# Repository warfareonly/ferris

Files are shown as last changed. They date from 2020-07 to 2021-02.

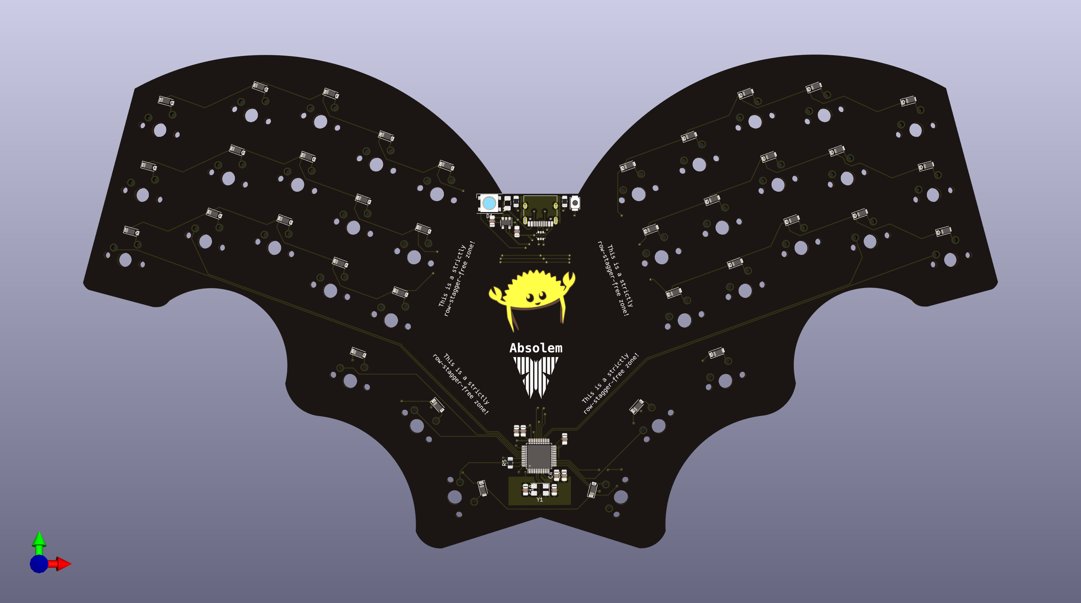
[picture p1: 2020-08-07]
absolem_layout/ferris_absolem_front.png

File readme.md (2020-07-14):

Meet Ferris, a minimalistic keyboard
====================================

Named after the Rustlang mascott, ferris is a 34 keys split keyboard that tries to be about as cute as its namesake.

Ferris
Ferris low front
Ferris low back

Ferris is minimalistic: it aims to be a functional, ergonomic keyboard that is pleasing to use as a daily driver. It only supports choc keyswitches, although it would be easy to make a MX version if there was interest.

It is fully Open-Source: the kicad files are released under [the solderpad license, version 2.1](LICENSE). The firmware, contributed to [the QMK project](https://github.com/qmk/qmk_firmware/) is released under the GPL.

Design philosophy
-----------------

The Ferris was designed around this set of goals:
* Comfort
* Aesthetics
* Portability
* Ease of assembly
* Low-Cost
* Low-Profile
* 34 keys
* Hackable
* USB-C
* No compromise

and this set of non-goals:
* Reversible PCB used for both hands
* Pro-micro/Elite C/Proton C support
* Hot-Swap support
* Multi-switches support
* Support for any feature (RGB, OLED, encoders, ...) that is not of interest to the user

You may read more about how each feature (and mostly lack thereof) contributes to these goals [in this write up](docs/design_philosophy.md) once described as "overly long and almost pretentious" :)

Technical details
-----------------

### Base variant, rev 0.1

This describes the first ever iteration of the Ferris keyboard: a plain pcb with support for choc switches, and the same layout as the Kyria (but limited to 34 keys).

* USB C
* 34 keys (3x5 + 2 thumb keys per hand)
* Split
* Atmega32u4 microcontroller on the left hand side
* MCP23017 on the right hand side
* A 4 poles jack cable carries data between halves using the i2c protocol
* The diodes live under the switches where they are snuggly hidden from sight
* No holes through the PCB. The intent is to use it case-less.
* Switches are spaced by 19mm from each other in each direction (almost exactly what's known as MX spacing [19.05x19.05]). This allows for a wider variety of compatible keycaps for the price of gaps for certain keycaps that respect the Kailh choc specification
* Columnar stagger identical to the one on the Kyria

### Ferris low variant, rev 0.1

* Same as the base variant with major change that the footprints are for Kailh PG1232 instead of choc for an even lower profile
* Copper pad adapted to ducking Ferris for theme
* Silkscreen changed to display schematics from the PG1232 switch
* Recommended PCB solder mask color is blue instead of white so the silkscreen gives vibes of a blueprint
* Name of the board updated to "Ferris low" instead of "Ferris"

### Upcoming changes

In rev 0.2, I would like to implement the following changes:

* Microcontroller: [Arm STM32F030F4P6TR](https://lcsc.com/product-detail/Others_STMicroelectronics_STM32F030F4P6TR_STMicroelectronics-STM32F030F4P6TR_C89040.html) instead of [Atmega32u4](https://lcsc.com/product-detail/ATMEL-AVR_ATMEL_ATMEGA32U4-AU_ATMEGA32U4-AU_C44854.html)
  * Cheaper: 0.83$ instead of $3.63, less unused pins, easier to solder, more flash, more ram, better rust support for possible pure rust firmware
* IO Expander: [PCA9539PW ](https://lcsc.com/product-detail/I-O-Expansion_NXP_PCA9539PW_PCA9539PW_C129516.html) instead of [MCP23017](https://lcsc.com/product-detail/Interface-ICs_MICROCHIP_MCP23017-E-SO_MCP23017-E-SO_C47023.html)
  * Cheaper 0.76$ instead of 1.56$
* Spacing: 0.18x0.19 instead of 0.19x0.19
  * Avoids gaps with keycaps that conform with the Kailh specifications
  * More ergonomic as fingers don't have to move as far up and down
  * Con: Looses compatibility to some keycaps
* Ferris MX:
  * I would like to also do a run with MX only footprints for anyone interested
* Ferris tent:
  * I would like to add four mounting holes on each hand to support the tenting puck that Thomas Baart at splitkb.com is currently designing

How to I print one?
-------------------

For a given version, you will find a release in this repository containing a zip file with the gerber files. This should be ready to send to a PCB manufacturer for assembly.
The repository also contains a bill of materials (bom.csv) with a list of the components you need and their reference number on LCSC.com. You may use another vendor for the components, as long as you make sure to get components that are equivalent.

How do I assemble one?
----------------------

Here is where the components go on the pcb:
components around the microcontroller
components around the usb c and the io expander

Most of these components are smd mounted. They can be soldered in with hot air and solder paste or with a soldering iron, solder wire and flux.
I have found it easier to control how much solder I use with a soldering iron.

Here are some key pieces of advice I can give from my experience assembling 3 of them so far:
* Be mindful of the orientation for the components that are polarized:
  * Diodes: cathode bar on the right side for both pcbs
  * Crystal: text readable looking at it from the controller
  * Controller: pin 1 dot indicator in the top right
  * IO expander: pin 1 dot indicator in the top left
* Use a wedge tip or other tip with a large enough surface. Pointy is harder.
* Don't use too much solder or you will have to wick it away and start again.
  * This especially applies to the USB C area and the microcontroller.
* Don't be shy on the flux: it really helps the solder flow where it should and keep away from surfaces it shouldn't go to.
* Don't use too much heat to avoid damaging the components. I've had good results with 350C for unleaded rosin core solder wire.
* Don't touch any component for too long with the iron to avoid heat damage. If you're not getting it right in a few seconds, let it cool down add more flux and try again. 
* Be sure to test every diode is properly soldered before soldering on the switches as the diodes are located under the switches and won't be accessible later on.
* I have found it easier to solder the crystal with hot air as it is hard to reach the solder from under it with an iron. Your mileage may vary

I took many pictures while building a board. If you want to build a Ferris while following along,
Part 1:
[build log, part 1](https://imgur.com/gallery/jYbxkxE)
Part 2:
[build log, part 2](https://imgur.com/gallery/gs19F6E)

Where is the firmware?
----------------------

For now, the Ferris keyboard is powered by QMK. Firmware for it is available [in this PR](https://github.com/qmk/qmk_firmware/pull/9634) and should make it upstream once the review process has taken its course.

The default keymap is very minimalistic. I will come up with something fancier in due time.

Status:
-------
v 0.1 is confirmed to work: I have printed 5 on jlcpcb.com and assembled 3. I have flashed the firmware on all of these and made sure that all keys are recognized as intended. I am also typing these words on a Ferris.

Here is a short demo of a working Ferris:
[typing test](https://i.imgur.com/E8Wipxz.mp4)

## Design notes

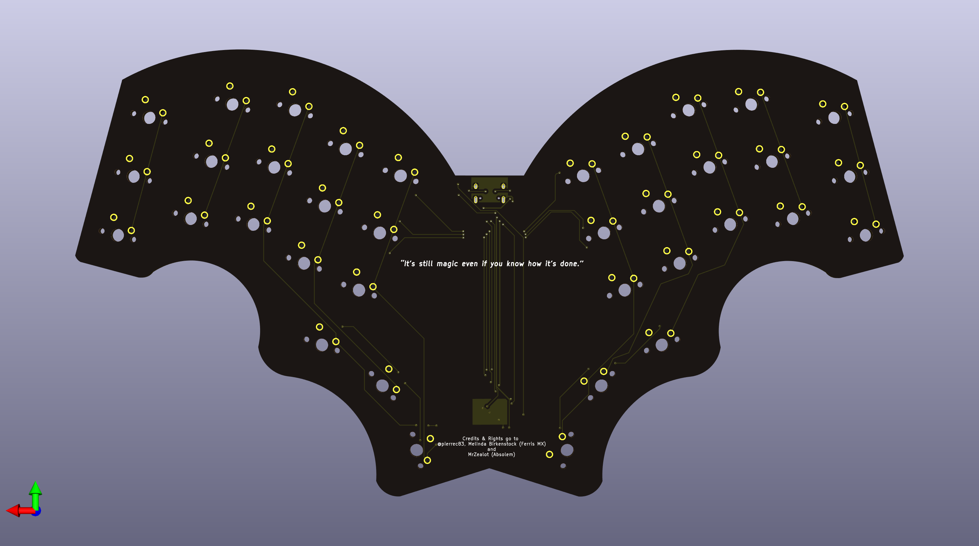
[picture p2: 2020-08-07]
absolem_layout/ferris_absolem_back.png

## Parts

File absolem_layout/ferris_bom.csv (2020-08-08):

Source: | /home/bharat/keyboard/ferris/absolem_layout/ferris.sch
Date: | Sat 08 Aug 2020 18:04:10 CEST
Tool: | Eeschema 5.1.6
Component Count: | 97
Ref | Value | Footprint | Datasheet | Manufacturer | Vendor
C1 | 1u | Capacitor_SMD:C_0805_2012Metric_Pad1.15x1.40mm_HandSolder | ~
C2 | 1u | Capacitor_SMD:C_0805_2012Metric_Pad1.15x1.40mm_HandSolder | ~
C3 | 1u | Capacitor_SMD:C_0805_2012Metric_Pad1.15x1.40mm_HandSolder | ~
C4 | 10n | Capacitor_SMD:C_0805_2012Metric_Pad1.15x1.40mm_HandSolder | ~
C5 | 4.7u | Capacitor_SMD:C_0805_2012Metric_Pad1.15x1.40mm_HandSolder | ~
C6 | 30p | Capacitor_SMD:C_0805_2012Metric_Pad1.15x1.40mm_HandSolder | ~
C7 | 100n | Capacitor_SMD:C_0805_2012Metric_Pad1.15x1.40mm_HandSolder | ~
C8 | 100n | Capacitor_SMD:C_0805_2012Metric_Pad1.15x1.40mm_HandSolder | ~
C9 | 100n | Capacitor_SMD:C_0805_2012Metric_Pad1.15x1.40mm_HandSolder | ~
C10 | 30p | Capacitor_SMD:C_0805_2012Metric_Pad1.15x1.40mm_HandSolder | ~
C11 | 4.7nF | Capacitor_SMD:C_0805_2012Metric_Pad1.15x1.40mm_HandSolder | ~
C12 | 10uF | Capacitor_SMD:C_0805_2012Metric_Pad1.15x1.40mm_HandSolder | ~
D0_1 | D | Diode_SMD:D_SOD-123 | ~
D0_2 | D | Diode_SMD:D_SOD-123 | ~
D0_3 | D | Diode_SMD:D_SOD-123 | ~
D0_4 | D | Diode_SMD:D_SOD-123 | ~
D0_5 | D | Diode_SMD:D_SOD-123 | ~
D0_6 | D | Diode_SMD:D_SOD-123 | ~
D0_7 | D | Diode_SMD:D_SOD-123 | ~
D0_8 | D | Diode_SMD:D_SOD-123 | ~
D0_9 | D | Diode_SMD:D_SOD-123 | ~
D0_10 | D | Diode_SMD:D_SOD-123 | ~
D1 | WS2812B | LED_SMD:LED_WS2812B_PLCC4_5.0x5.0mm_P3.2mm | https://cdn-shop.adafruit.com/datasheets/WS2812B.pdf
D1_1 | D | Diode_SMD:D_SOD-123 | ~
D1_2 | D | Diode_SMD:D_SOD-123 | ~
D1_3 | D | Diode_SMD:D_SOD-123 | ~
D1_4 | D | Diode_SMD:D_SOD-123 | ~
D1_5 | D | Diode_SMD:D_SOD-123 | ~
D1_6 | D | Diode_SMD:D_SOD-123 | ~
D1_7 | D | Diode_SMD:D_SOD-123 | ~
D1_8 | D | Diode_SMD:D_SOD-123 | ~
D1_9 | D | Diode_SMD:D_SOD-123 | ~
D1_10 | D | Diode_SMD:D_SOD-123 | ~
D1_11 | D | Diode_SMD:D_SOD-123 | ~
D2_1 | D | Diode_SMD:D_SOD-123 | ~
D2_2 | D | Diode_SMD:D_SOD-123 | ~
D2_3 | D | Diode_SMD:D_SOD-123 | ~
D2_4 | D | Diode_SMD:D_SOD-123 | ~
D2_5 | D | Diode_SMD:D_SOD-123 | ~
D2_6 | D | Diode_SMD:D_SOD-123 | ~
D2_7 | D | Diode_SMD:D_SOD-123 | ~
D2_8 | D | Diode_SMD:D_SOD-123 | ~
D2_9 | D | Diode_SMD:D_SOD-123 | ~
D2_10 | D | Diode_SMD:D_SOD-123 | ~
D3_1 | D | Diode_SMD:D_SOD-123 | ~
D3_2 | D | Diode_SMD:D_SOD-123 | ~
D3_3 | D | Diode_SMD:D_SOD-123 | ~
D3_4 | D | Diode_SMD:D_SOD-123 | ~
D3_5 | D | Diode_SMD:D_SOD-123 | ~
D3_6 | D | Diode_SMD:D_SOD-123 | ~
F1 | 500mA | Fuse:Fuse_1206_3216Metric | ~
IC1 | NUF2221W1T2G | SOT-363 | Good
J1 | USB C | Connector_USB:USB_C_Receptacle_HRO_TYPE-C-31-M-12 | https://www.usb.org/sites/default/files/documents/usb_type-c.zip
K0_1 | KEYSW | MX:MXOnly-1U-NoLED
K0_2 | KEYSW | MX:MXOnly-1U-NoLED
K0_3 | KEYSW | MX:MXOnly-1U-NoLED
K0_4 | KEYSW | MX:MXOnly-1U-NoLED
K0_5 | KEYSW | MX:MXOnly-1U-NoLED
K0_6 | KEYSW | MX:MXOnly-1U-NoLED
K0_7 | KEYSW | MX:MXOnly-1U-NoLED
K0_8 | KEYSW | MX:MXOnly-1U-NoLED
K0_9 | KEYSW | MX:MXOnly-1U-NoLED
K0_10 | KEYSW | MX:MXOnly-1U-NoLED
K1_1 | KEYSW | MX:MXOnly-1U-NoLED
K1_2 | KEYSW | MX:MXOnly-1U-NoLED
K1_3 | KEYSW | MX:MXOnly-1U-NoLED
K1_4 | KEYSW | MX:MXOnly-1U-NoLED
K1_5 | KEYSW | MX:MXOnly-1U-NoLED
K1_6 | KEYSW | MX:MXOnly-1U-NoLED
K1_7 | KEYSW | MX:MXOnly-1U-NoLED
K1_8 | KEYSW | MX:MXOnly-1U-NoLED
K1_9 | KEYSW | MX:MXOnly-1U-NoLED
K1_10 | KEYSW | MX:MXOnly-1U-NoLED
K2_1 | KEYSW | MX:MXOnly-1U-NoLED
K2_2 | KEYSW | MX:MXOnly-1U-NoLED
K2_3 | KEYSW | MX:MXOnly-1U-NoLED
K2_4 | KEYSW | MX:MXOnly-1U-NoLED
K2_5 | KEYSW | MX:MXOnly-1U-NoLED
K2_6 | KEYSW | MX:MXOnly-1U-NoLED
K2_7 | KEYSW | MX:MXOnly-1U-NoLED
K2_8 | KEYSW | MX:MXOnly-1U-NoLED
K2_9 | KEYSW | MX:MXOnly-1U-NoLED
K2_10 | KEYSW | MX:MXOnly-1U-NoLED
K3_1 | KEYSW | MX:MXOnly-1U-NoLED
K3_2 | KEYSW | MX:MXOnly-1U-NoLED
K3_3 | KEYSW | MX:MXOnly-1U-NoLED
K3_4 | KEYSW | MX:MXOnly-1U-NoLED
K3_5 | KEYSW | MX:MXOnly-1U-NoLED
K3_6 | KEYSW | MX:MXOnly-1U-NoLED
Q1 | DTC123J | Package_TO_SOT_SMD:SOT-23
R1 | 5.1K | Resistor_SMD:R_0805_2012Metric_Pad1.15x1.40mm_HandSolder | ~
R2 | 5.1K | Resistor_SMD:R_0805_2012Metric_Pad1.15x1.40mm_HandSolder | ~
R5 | 10k | Resistor_SMD:R_0805_2012Metric_Pad1.15x1.40mm_HandSolder | ~
SW1 | SW_PUSH | Button_Switch_SMD:SW_SPST_B3U-1000P
U1 | TLV70012_SOT23-5 | Package_TO_SOT_SMD:SOT-23-5 | http://www.ti.com/lit/ds/symlink/tlv700.pdf
U2 | STM32F303CBTx | Package_QFP:LQFP-48_7x7mm_P0.5mm | http://www.st.com/st-web-ui/static/active/en/resource/technical/document/datasheet/DM00058181.pdf
Y1 | 8MHz | Crystal:Crystal_SMD_5032-4Pin_5.0x3.2mm | ~

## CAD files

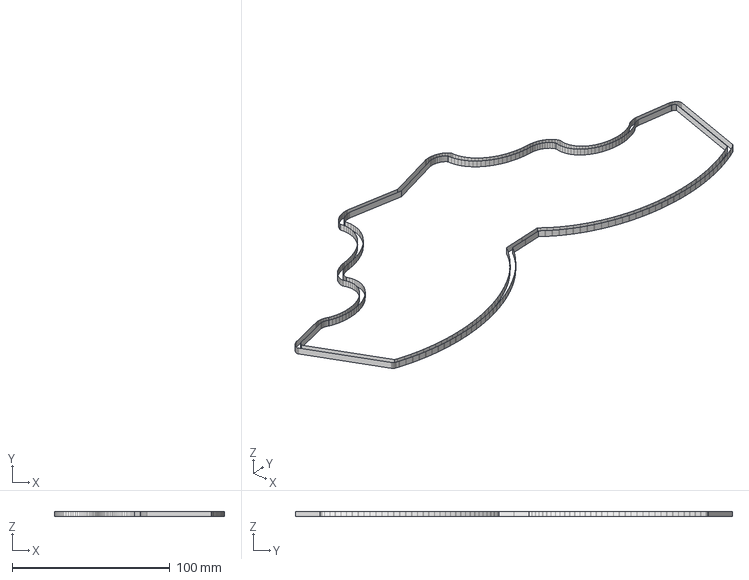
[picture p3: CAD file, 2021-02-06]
absolem_layout/gerber/3dcase.FCStd
107.8 x 277.5 x 3.00 mm

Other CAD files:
absolem_layout/gerber/3dcase.stl

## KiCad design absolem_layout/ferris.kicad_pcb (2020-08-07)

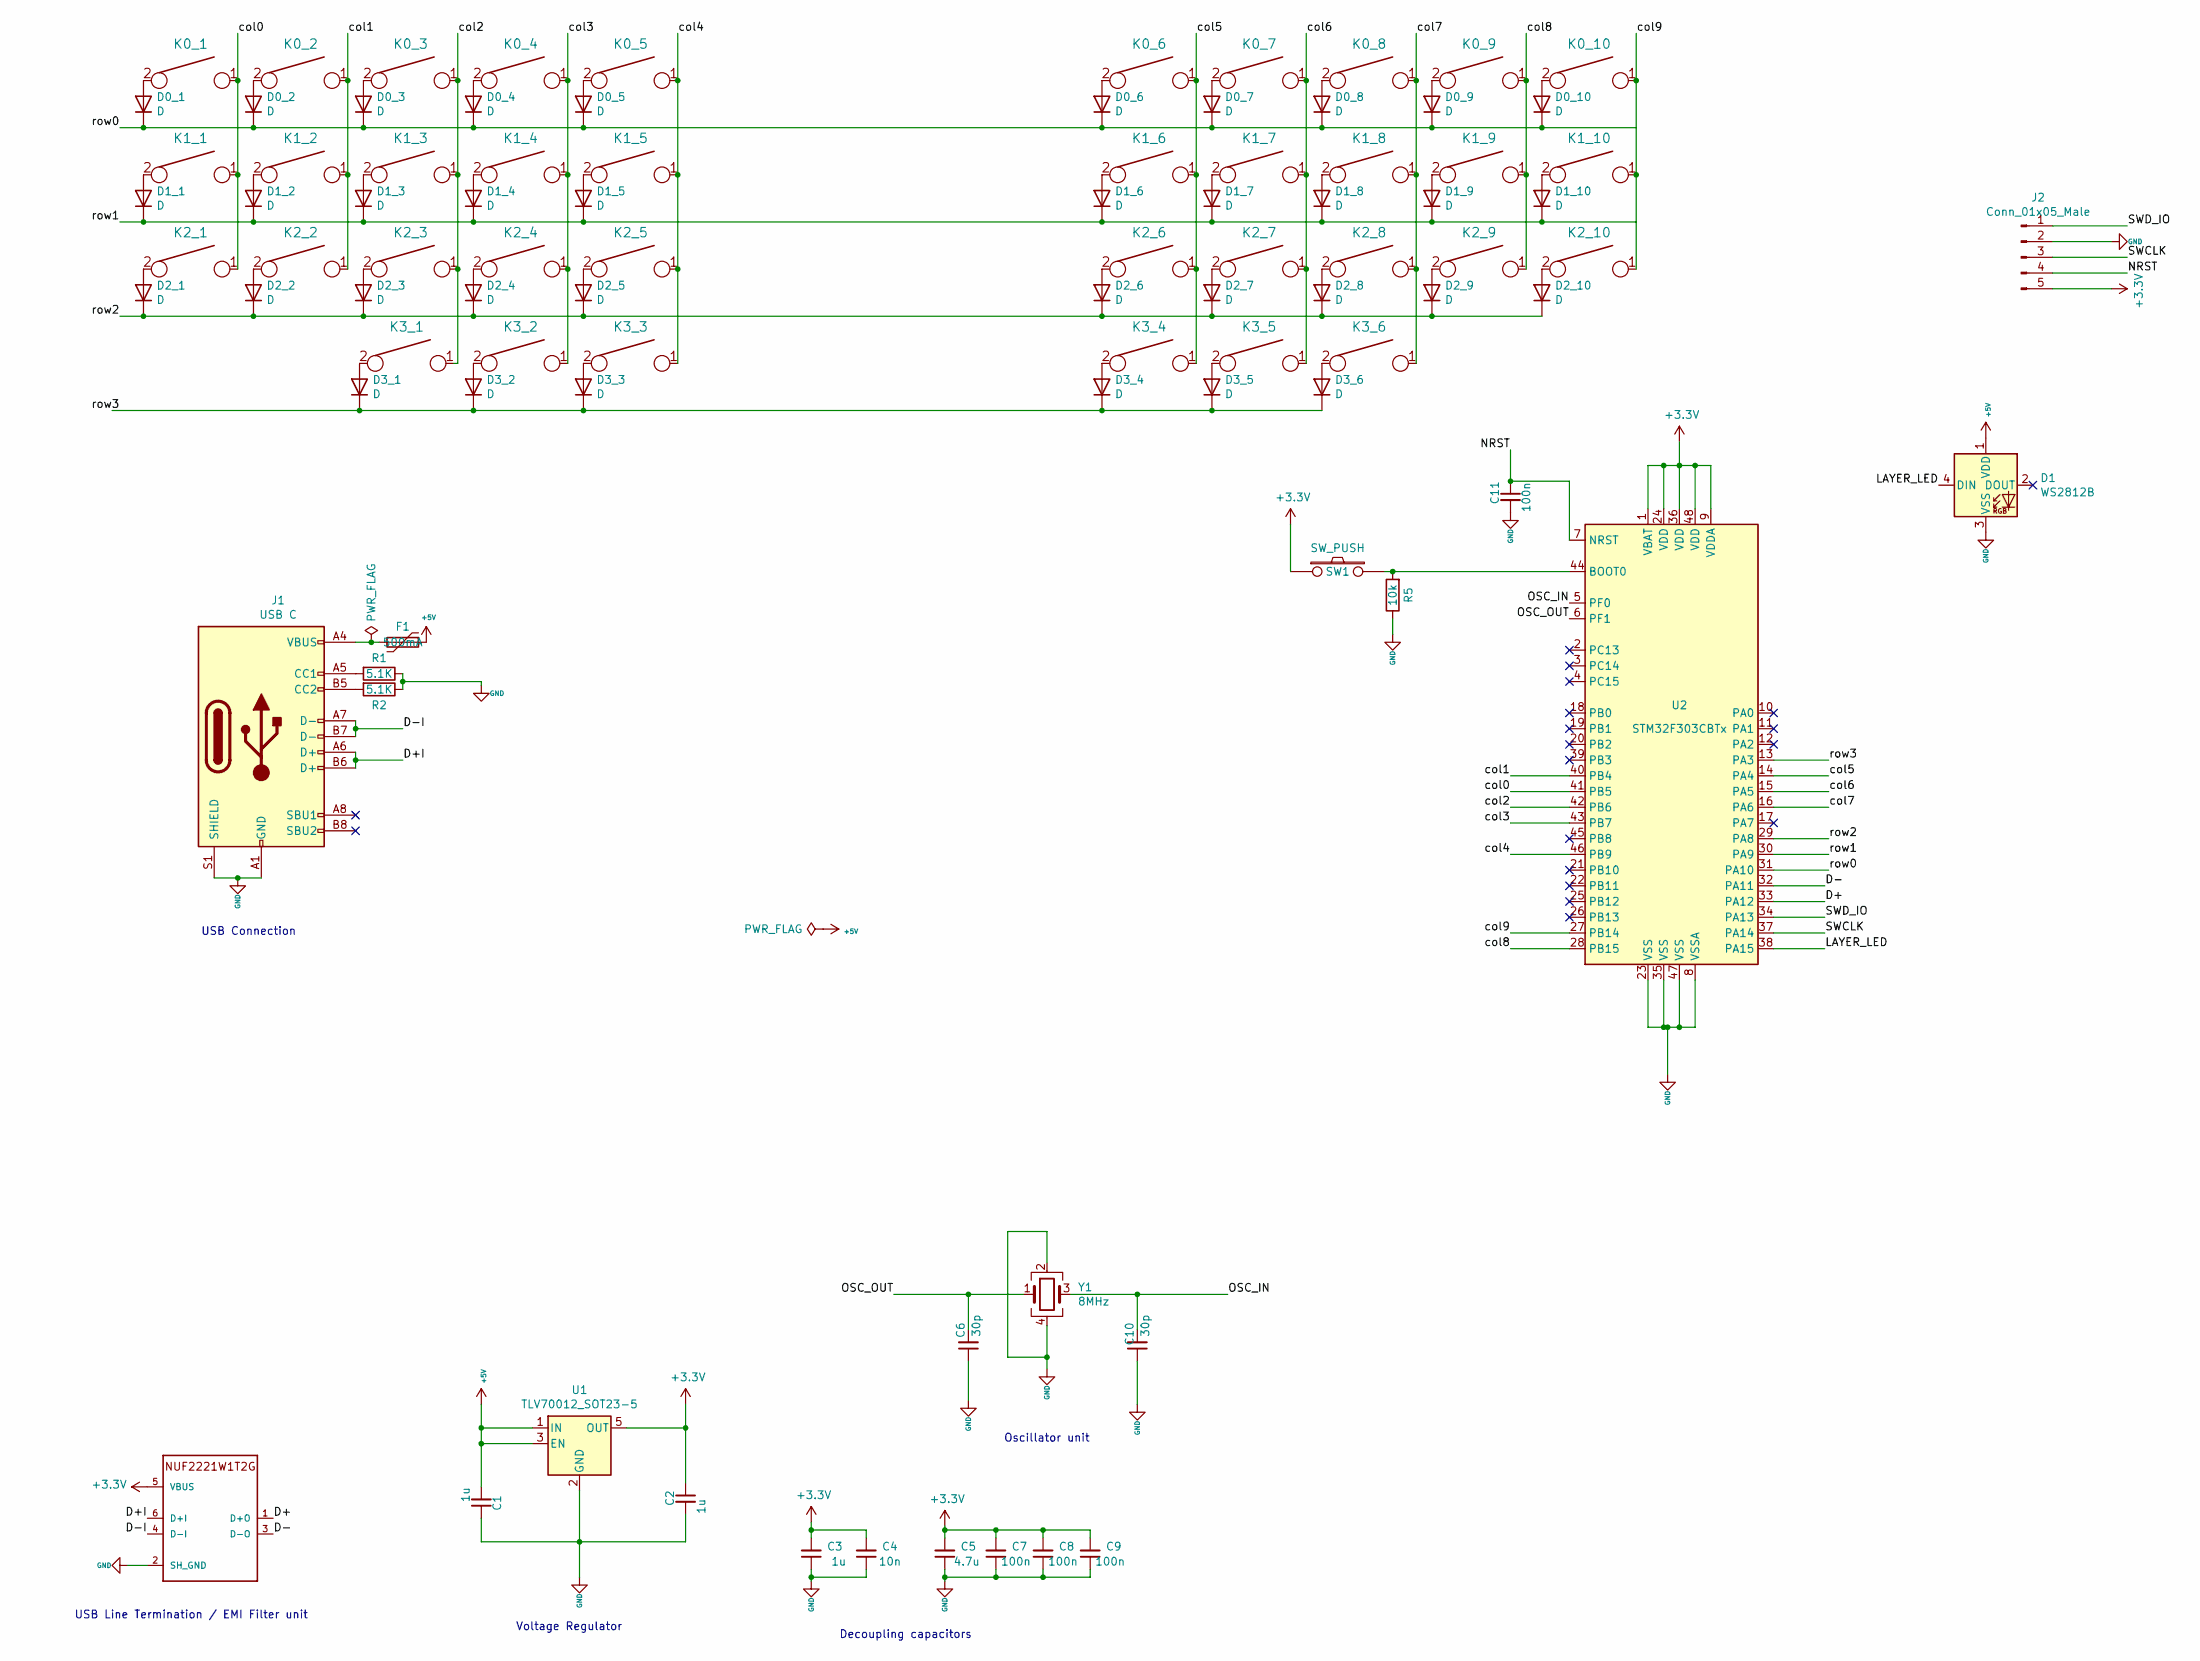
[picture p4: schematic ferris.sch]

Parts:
C1, C2: 1u; C_0805_2012Metric_Pad1.15x1.40mm_HandSolder; LCSC Part # C49678
C3: 1u; C_0805_2012Metric_Pad1.15x1.40mm_HandSolder
C4: 10n; C_0805_2012Metric_Pad1.15x1.40mm_HandSolder
C5: 4.7u; C_0805_2012Metric_Pad1.15x1.40mm_HandSolder
C6, C10: 30p; C_0805_2012Metric_Pad1.15x1.40mm_HandSolder
C7, C8, C9: 100n; C_0805_2012Metric_Pad1.15x1.40mm_HandSolder
C11: 100n; C_0805_2012Metric_Pad1.15x1.40mm_HandSolder; LCSC Part # C49678
D0_1: D; D_SOD-123; LCSC Part # C81598
D0_2, D0_3, D0_4, D0_5, D0_6, D0_7, D0_8, D0_9, D0_10, D1_1, D1_2, D1_3, D1_4, D1_5, D1_6, D1_7, D1_8, D1_9, D1_10, D2_1, D2_2, D2_3, D2_4, D2_5, D2_6, D2_7, D2_8, D2_9, D2_10, D3_1, D3_2, D3_3, D3_4, D3_5, D3_6: D; D_SOD-123
D1: WS2812B; LED_WS2812B_PLCC4_5.0x5.0mm_P3.2mm
F1: 500mA; Fuse_1206_3216Metric; LCSC Part # C151162
IC1: NUF2221W1T2G; SOT-363
J1: USB C; USB_C_Receptacle_HRO_TYPE-C-31-M-12; LCSC Part # C165948
J2: Conn_01x05_Male; PinHeader_1x05_P2.54mm_Vertical
K0_1: KEYSW; MXOnly-1U-NoLED; LCSC Part # C489144
K0_2, K0_3, K0_4, K0_5, K0_6, K0_7, K0_8, K0_9, K0_10, K1_1, K1_2, K1_3, K1_4, K1_5, K1_6, K1_7, K1_8, K1_9, K1_10, K2_1, K2_2, K2_3, K2_4, K2_5, K2_6, K2_7, K2_8, K2_9, K2_10, K3_1, K3_2, K3_3, K3_4, K3_5, K3_6: KEYSW; MXOnly-1U-NoLED
R1: 5.1K; R_0805_2012Metric_Pad1.15x1.40mm_HandSolder; LCSC Part # C27834
R2: 5.1K; R_0805_2012Metric_Pad1.15x1.40mm_HandSolder
R5: 10k; R_0805_2012Metric_Pad1.15x1.40mm_HandSolder; LCSC Part # C17414
SW1: SW_PUSH; SW_SPST_B3U-1000P; LCSC Part # C231329
U1: TLV70012_SOT23-5; SOT-23-5
U2: STM32F303CBTx; LQFP-48_7x7mm_P0.5mm
Y1: 8MHz; Crystal_SMD_5032-4Pin_5.0x3.2mm

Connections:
+3V3: C2.1, C3.2, C4.2, C5.2, C7.2, C8.2, C9.2, IC1.5 (VBUS), J2.5, SW1.1, U1.5 (OUT), U2.1 (VBAT), U2.9 (VDDA), U2.24 (VDD), U2.36 (VDD), U2.48 (VDD)
+5V: C1.2, D1.1 (VDD), F1.1, U1.1 (IN), U1.3 (EN)
/D+: IC1.1 (D+O), U2.33 (PA12)
/D+I: IC1.6 (D+I), J1.A6 (D+), J1.B6 (D+)
/D-: IC1.3 (D-O), U2.32 (PA11)
/D-I: IC1.4 (D-I), J1.A7 (D-), J1.B7 (D-)
/LAYER_LED: D1.4 (DIN), U2.38 (PA15)
/NRST: C11.1, J2.4, U2.7 (NRST)
/OSC_IN: C10.2, U2.5 (PF0), Y1.3
/OSC_OUT: C6.2, U2.6 (PF1), Y1.1
/SWCLK: J2.3, U2.37 (PA14)
/SWD_IO: J2.1, U2.34 (PA13)
/col0: K0_1.1, K1_1.1, K2_1.1, U2.41 (PB5)
/col1: K0_2.1, K1_2.1, K2_2.1, U2.40 (PB4)
/col2: K0_3.1, K1_3.1, K2_3.1, K3_1.1, U2.42 (PB6)
/col3: K0_4.1, K1_4.1, K2_4.1, K3_2.1, U2.43 (PB7)
/col4: K0_5.1, K1_5.1, K2_5.1, K3_3.1, U2.46 (PB9)
/col5: K0_6.1, K1_6.1, K2_6.1, K3_4.1, U2.14 (PA4)
/col6: K0_7.1, K1_7.1, K2_7.1, K3_5.1, U2.15 (PA5)
/col7: K0_8.1, K1_8.1, K2_8.1, K3_6.1, U2.16 (PA6)
/col8: K0_9.1, K1_9.1, K2_9.1, U2.28 (PB15)
/col9: K0_10.1, K1_10.1, K2_10.1, U2.27 (PB14)
/row0: D0_1.1 (K), D0_2.1 (K), D0_3.1 (K), D0_4.1 (K), D0_5.1 (K), D0_6.1 (K), D0_7.1 (K), D0_8.1 (K), D0_9.1 (K), D0_10.1 (K), U2.31 (PA10)
/row1: D1_1.1 (K), D1_2.1 (K), D1_3.1 (K), D1_4.1 (K), D1_5.1 (K), D1_6.1 (K), D1_7.1 (K), D1_8.1 (K), D1_9.1 (K), D1_10.1 (K), U2.30 (PA9)
/row2: D2_1.1 (K), D2_2.1 (K), D2_3.1 (K), D2_4.1 (K), D2_5.1 (K), D2_6.1 (K), D2_7.1 (K), D2_8.1 (K), D2_9.1 (K), D2_10.1 (K), U2.29 (PA8)
/row3: D3_1.1 (K), D3_2.1 (K), D3_3.1 (K), D3_4.1 (K), D3_5.1 (K), D3_6.1 (K), U2.13 (PA3)
GND: C1.1, C2.2, C3.1, C4.1, C5.1, C6.1, C7.1, C8.1, C9.1, C10.1, C11.2, D1.3 (VSS), IC1.2 (SH_GND), J1.A1 (GND), J1.A12 (GND), J1.B1 (GND), J1.B12 (GND), J1.S1 (SHIELD), J2.2, R1.1, R2.1, R5.1, U1.2 (GND), U2.8 (VSSA), U2.23 (VSS), U2.35 (VSS), U2.47 (VSS), Y1.2, Y1.4
unnamed: D0_1.2 (A), K0_1.2
unnamed: D0_2.2 (A), K0_2.2
unnamed: D0_3.2 (A), K0_3.2
unnamed: D0_4.2 (A), K0_4.2
unnamed: D0_5.2 (A), K0_5.2
unnamed: D0_6.2 (A), K0_6.2
unnamed: D0_7.2 (A), K0_7.2
unnamed: D0_8.2 (A), K0_8.2
unnamed: D0_9.2 (A), K0_9.2
unnamed: D0_10.2 (A), K0_10.2
unnamed: D1_1.2 (A), K1_1.2
unnamed: D1_2.2 (A), K1_2.2
unnamed: D1_3.2 (A), K1_3.2
unnamed: D1_4.2 (A), K1_4.2
unnamed: D1_5.2 (A), K1_5.2
unnamed: D1_6.2 (A), K1_6.2
unnamed: D1_7.2 (A), K1_7.2
unnamed: D1_8.2 (A), K1_8.2
unnamed: D1_9.2 (A), K1_9.2
unnamed: D1_10.2 (A), K1_10.2
unnamed: D2_1.2 (A), K2_1.2
unnamed: D2_2.2 (A), K2_2.2
unnamed: D2_3.2 (A), K2_3.2
unnamed: D2_4.2 (A), K2_4.2
unnamed: D2_5.2 (A), K2_5.2
unnamed: D2_6.2 (A), K2_6.2
unnamed: D2_7.2 (A), K2_7.2
unnamed: D2_8.2 (A), K2_8.2
unnamed: D2_9.2 (A), K2_9.2
unnamed: D2_10.2 (A), K2_10.2
unnamed: D3_1.2 (A), K3_1.2
unnamed: D3_2.2 (A), K3_2.2
unnamed: D3_3.2 (A), K3_3.2
unnamed: D3_4.2 (A), K3_4.2
unnamed: D3_5.2 (A), K3_5.2
unnamed: D3_6.2 (A), K3_6.2
unnamed: F1.2, J1.A4 (VBUS), J1.A9 (VBUS), J1.B4 (VBUS), J1.B9 (VBUS)
unnamed: J1.A5 (CC1), R1.2
unnamed: J1.B5 (CC2), R2.2
unnamed: R5.2, SW1.2, U2.44 (BOOT0)

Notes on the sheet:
Voltage Regulator
USB Line Termination / EMI Filter unit
Oscillator unit
Decoupling capacitors
USB Connection

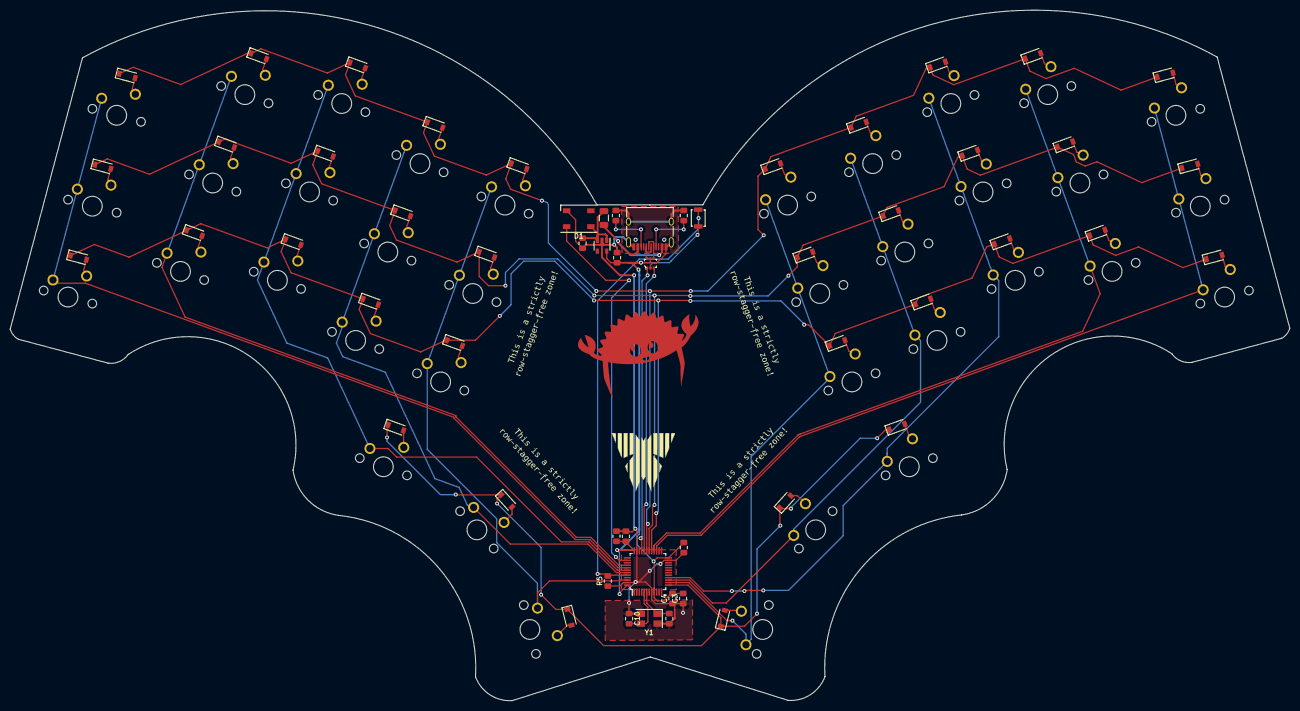
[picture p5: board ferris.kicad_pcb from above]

Board: 2 copper layers, 258.4 x 139.4 mm, 93 parts (0 on the bottom side), 64 nets.

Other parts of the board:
GFRONT: LOGO; front

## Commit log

2020-07-14 Design the "Ferris low" variant
    * Same as the base variant with major change that the footprints are
    for Kailh PG1232 instead of choc for an even lower profile
    * Copper pad adapted to ducking Ferris for theme
    * Silkscreen changed to display schematics from the PG1232 switch
    * Recommended PCB solder mask color is blue instead of white so the
    silkscreen gives vibes of a blueprint
    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
    [ferris.kicad_pcb, ferris.sch]
2020-07-15 Update silkscreen text to credit bomtarnes and for uppercasing Low
    [ferris.kicad_pcb]
2020-07-15 Position credits a bit better
    [ferris.kicad_pcb]
2020-07-30 Added LED on LHS
    [ferris.kicad_pcb, ferris.sch]
2020-07-31 Moved I2C resistors to RHS, moved LED
    [ferris.kicad_pcb, ferris.sch]
2020-07-31 Replaced MCP23017 with PCA9539PW
    [ferris.kicad_pcb, ferris.sch]
2020-07-31 Repositioned the components near the inner edges
    [ferris.kicad_pcb, ferris.sch]
2020-07-31 Fixed a minor DRC error
    [ferris.kicad_pcb]
2020-08-01 Cleaned up some tracks. Final stuff editing now
    [ferris.kicad_pcb]
2020-08-04 Rotated pinky col
    [ferris.kicad_pcb]
2020-08-05 Added a version with the Absolem layout
    [ferris.kicad_pcb, ferris.sch]
2020-08-05 Fixed some staggering
    [ferris.kicad_pcb, ferris.sch]
2020-08-05 Fixed some minor routing and silksscreen
    [ferris.kicad_pcb, ferris.sch]
2020-08-06 Computer change
    [familylist_refdes.csv, ferris.kicad_pcb, ferris.sch]
2020-08-06 Devid commit
    [ferris.kicad_pcb, ferris.sch]
2020-08-06 Oscillator added to the schematic.
    [ferris.sch]
2020-08-06 Deivid changes.
    [ferris.sch]
2020-08-06 More labelling
    [ferris.sch]
2020-08-06 More connections, removed line termination resistors (now we use an IC for it!)
    [ferris.sch]
2020-08-06 Connected up most of the power. PCB incomplete still
    [ferris.kicad_pcb, ferris.sch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]
2020-08-07 Updated the routing and positons
    [ferris.kicad_pcb, ferris.sch]
2020-08-08 Prefinal version
    [ferris.sch, ferris_bom.csv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]
2020-08-08 Loose trace fixed.
    [ferris-job.gbrjob, ferris.drl]
2020-08-08 Final version
    [ferris-job.gbrjob, ferris.drl]
